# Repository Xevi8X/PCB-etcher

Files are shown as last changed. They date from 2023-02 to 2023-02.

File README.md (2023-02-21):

# PCB-etcher

This is the project of a small, but powerful thermostat based on ESP01 with phase controlled output and simple web application. Implements bang-bang controller with hysteresis, PID controller with anti-windup feature and autotune (hopefully, in future). Thermostat was design to control temperature in DIY PCB Etcher.

Project contains source code and electric circuit with PCB project, design in EAGLE PCB.

### Web application:

##### Info screen:
info

##### Charts:
chart

##### Controller setting:
controller

### Device:




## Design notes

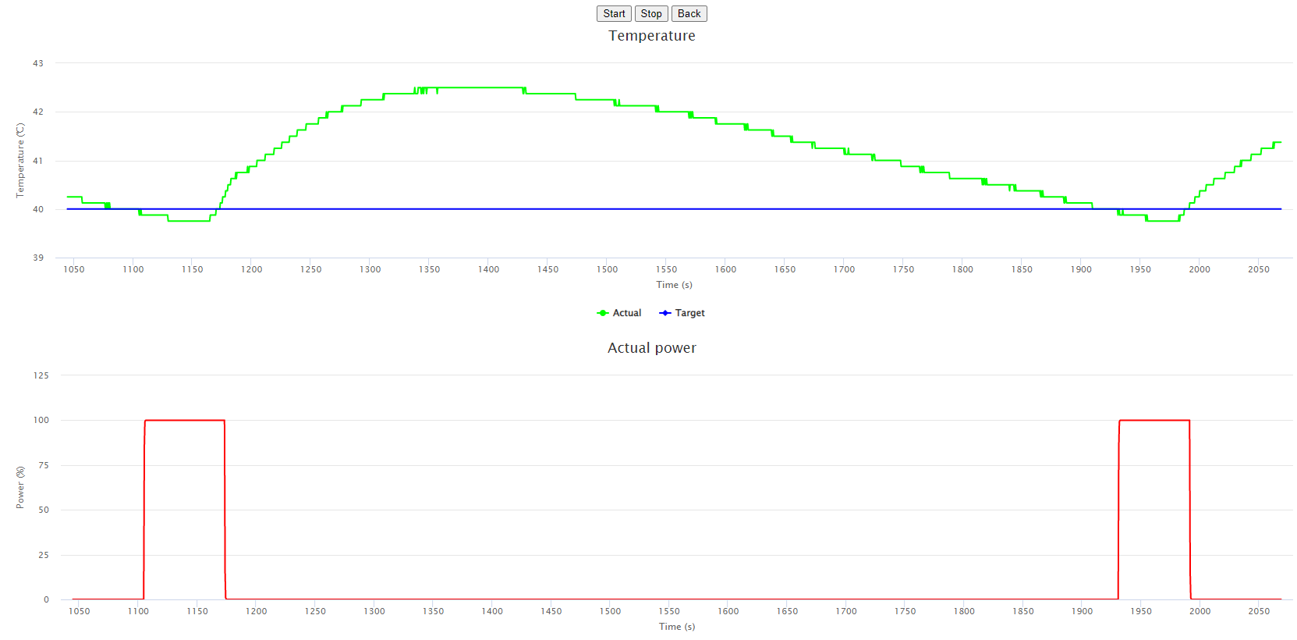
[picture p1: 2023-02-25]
docs/bang_bang_charts.png

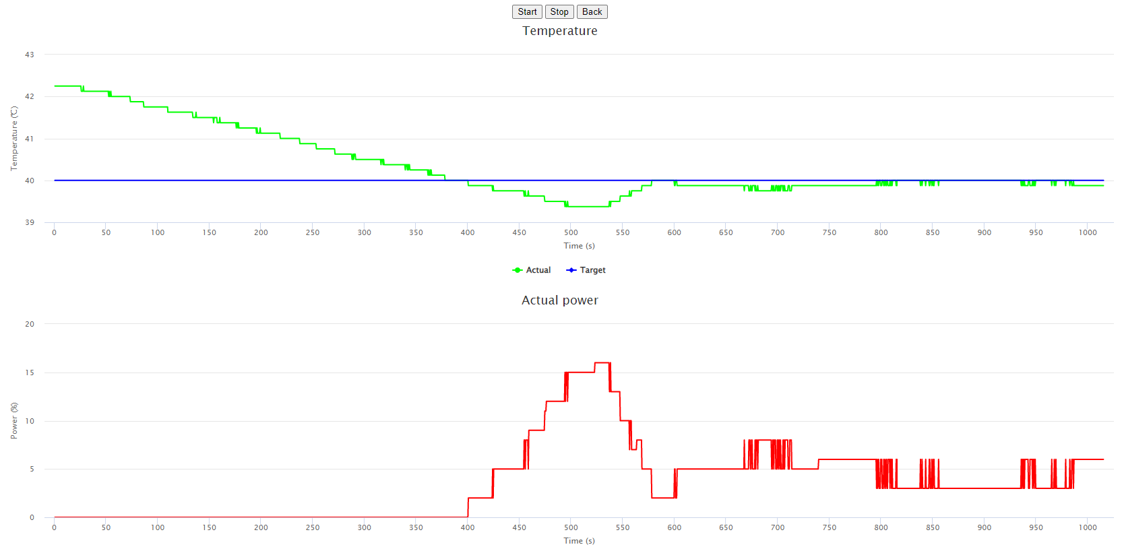
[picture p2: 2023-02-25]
docs/pid_charts.png

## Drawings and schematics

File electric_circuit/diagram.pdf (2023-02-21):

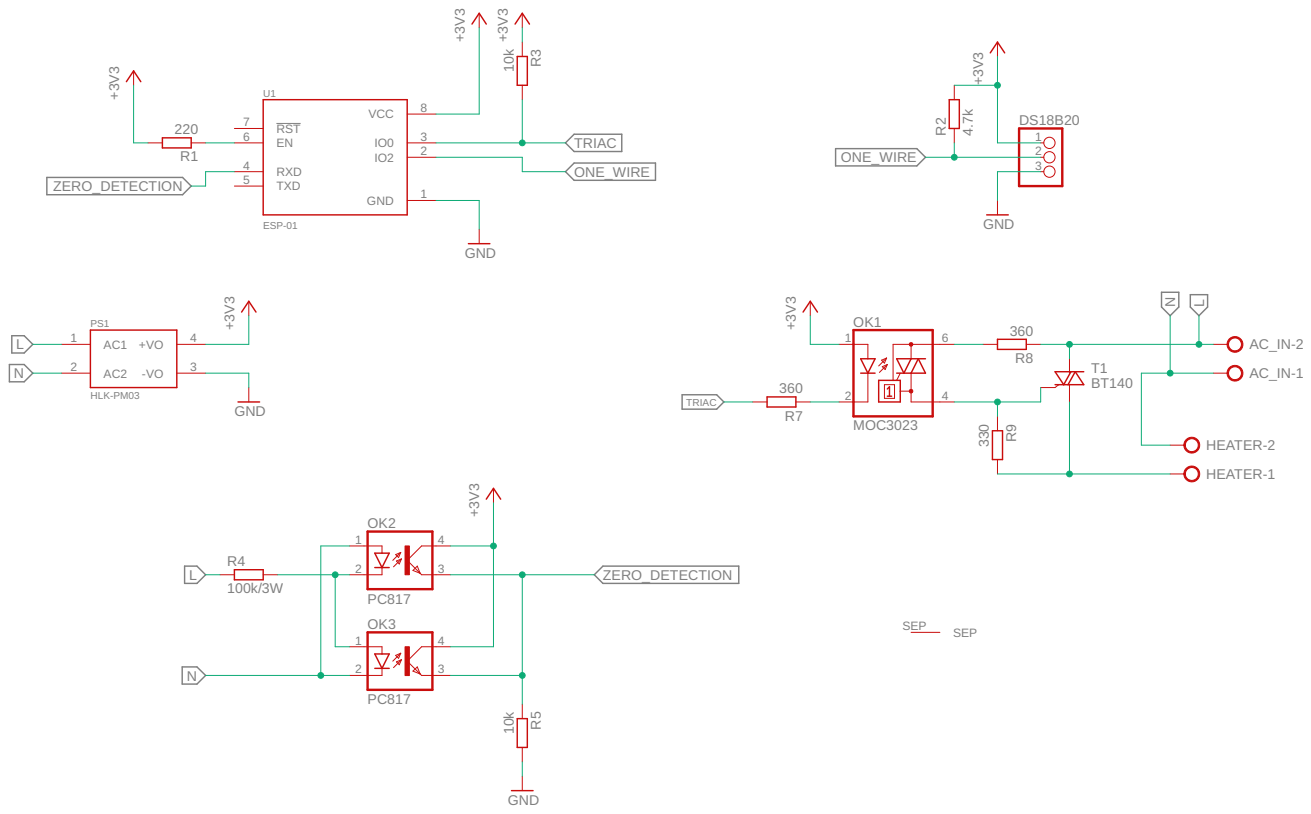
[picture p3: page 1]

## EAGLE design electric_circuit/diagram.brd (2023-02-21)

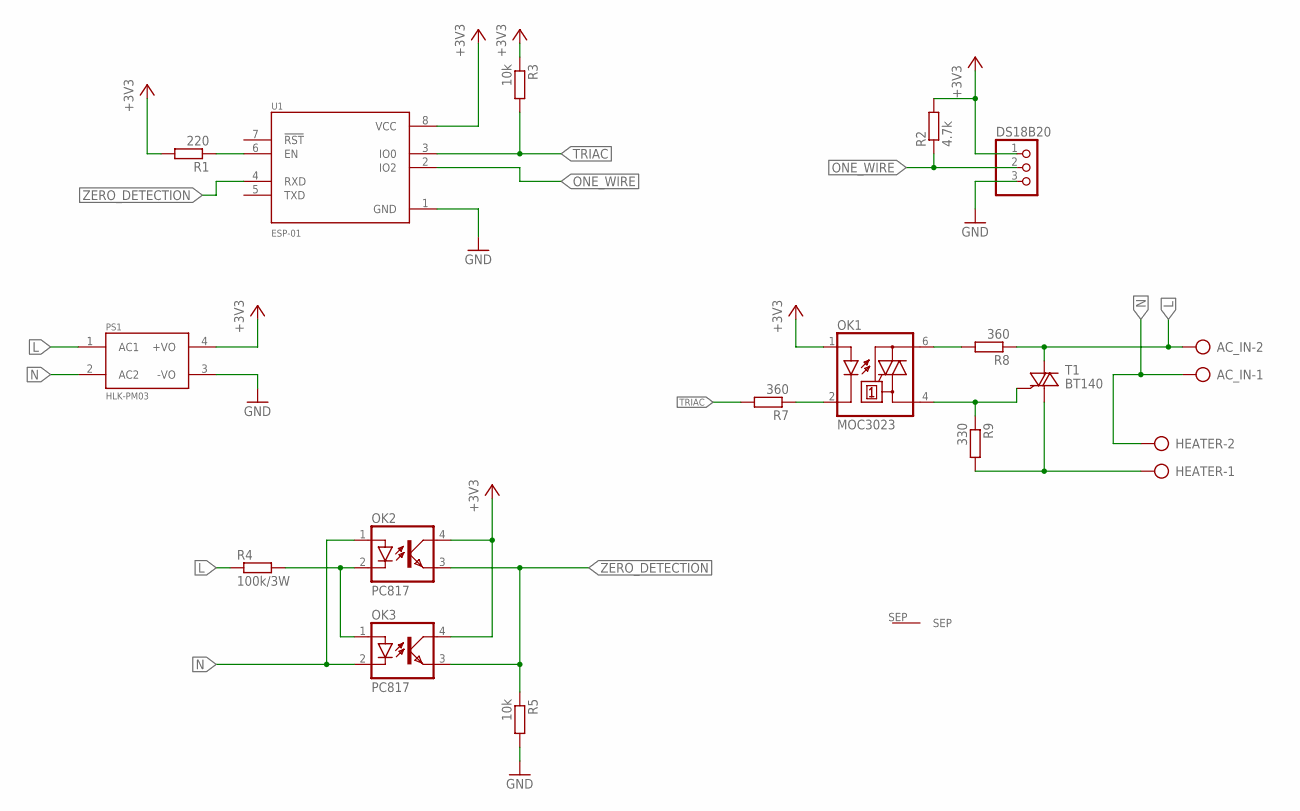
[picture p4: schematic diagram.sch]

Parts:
AC_IN: AK300/2
DS18B20: PINHD-1X3; 1X03
HEATER: AK300/2
OK1: MOC3023; DIL06
OK2, OK3: PC817; DIL04
PS1: HLK-PM03; CONV_HLK-PM03
R1: 220; R1206
R2: 4.7k; R1206
R3: 10k; 0204/5
R4: 100k/3W; 0414/15
R5: 10k; 0204/7
R7, R8: 360; M1206
R9: 330; M1206
T1: BT140; TO220BV
U1: ESP-01; XCVR_ESP8266-01/ESP-01
U$1: TEST; V7142

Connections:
+3V3: DS18B20.1, OK1.1 (A), OK2.4 (COL), OK3.4 (COL), PS1.4 (+VO), R1.2, R2.2, R3.1, U1.8 (VCC)
GND: DS18B20.3, PS1.3 (-VO), R5.2, U1.1 (GND)
L: AC_IN.2, PS1.1 (AC1), R4.1, R8.1, T1.T2 (A2)
N: AC_IN.1, HEATER.2, OK2.1 (A), OK3.2 (C), PS1.2 (AC2)
unnamed: R1.1, U1.6 (EN)
unnamed: OK2.2 (C), OK3.1 (A), R4.2
unnamed: OK1.6 (A2), R8.2
unnamed: OK1.4 (A1), R9.1, T1.G
unnamed: HEATER.1, R9.2, T1.T1 (A1)
unnamed: OK1.2 (C), R7.1
ONE_WIRE: DS18B20.2, R2.1, U1.2 (IO2)
TRIAC: R3.2, R7.2, U1.3 (IO0)
ZERO_DETECTION: OK2.3 (EMIT), OK3.3 (EMIT), R5.1, U1.4 (RXD)

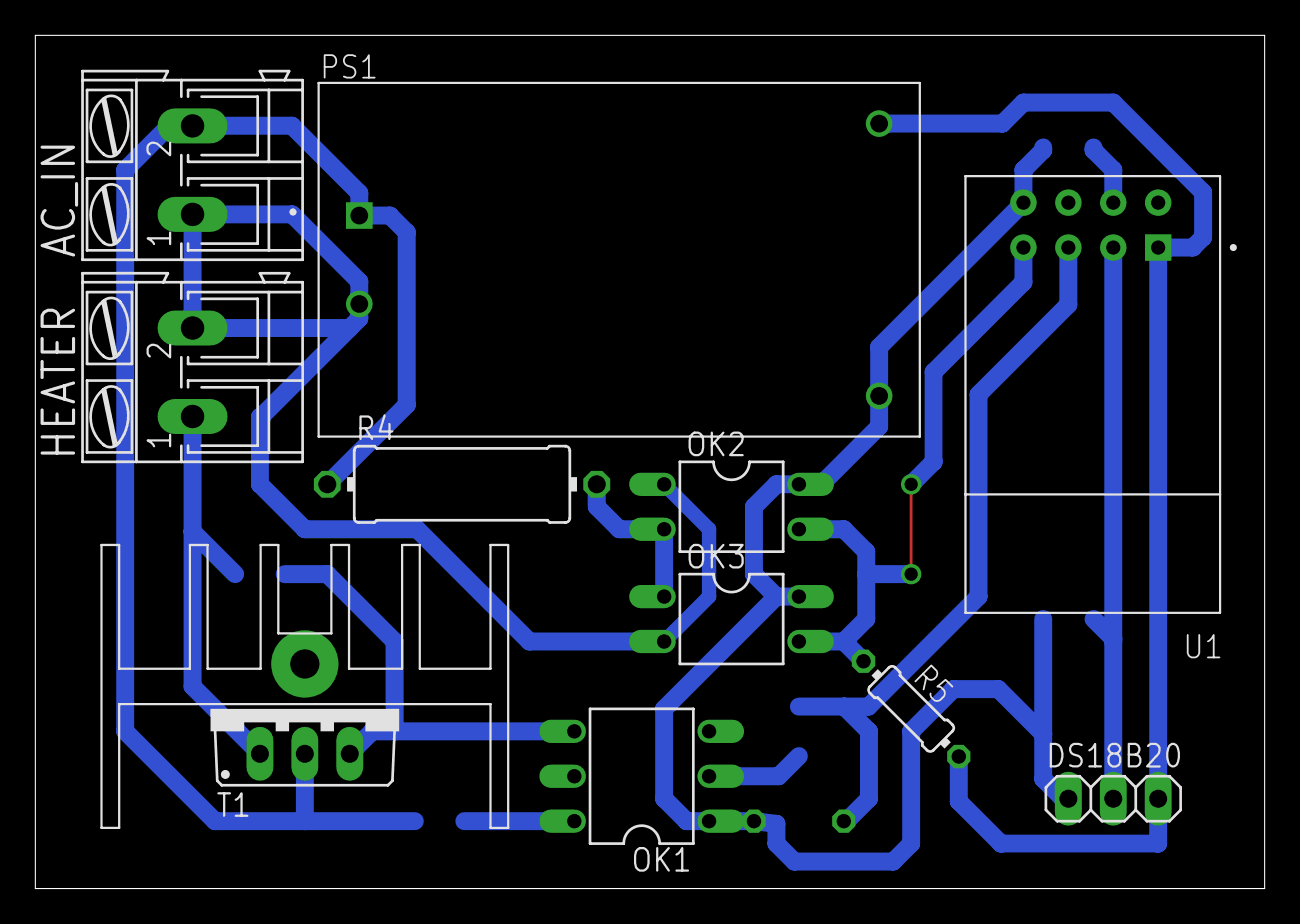
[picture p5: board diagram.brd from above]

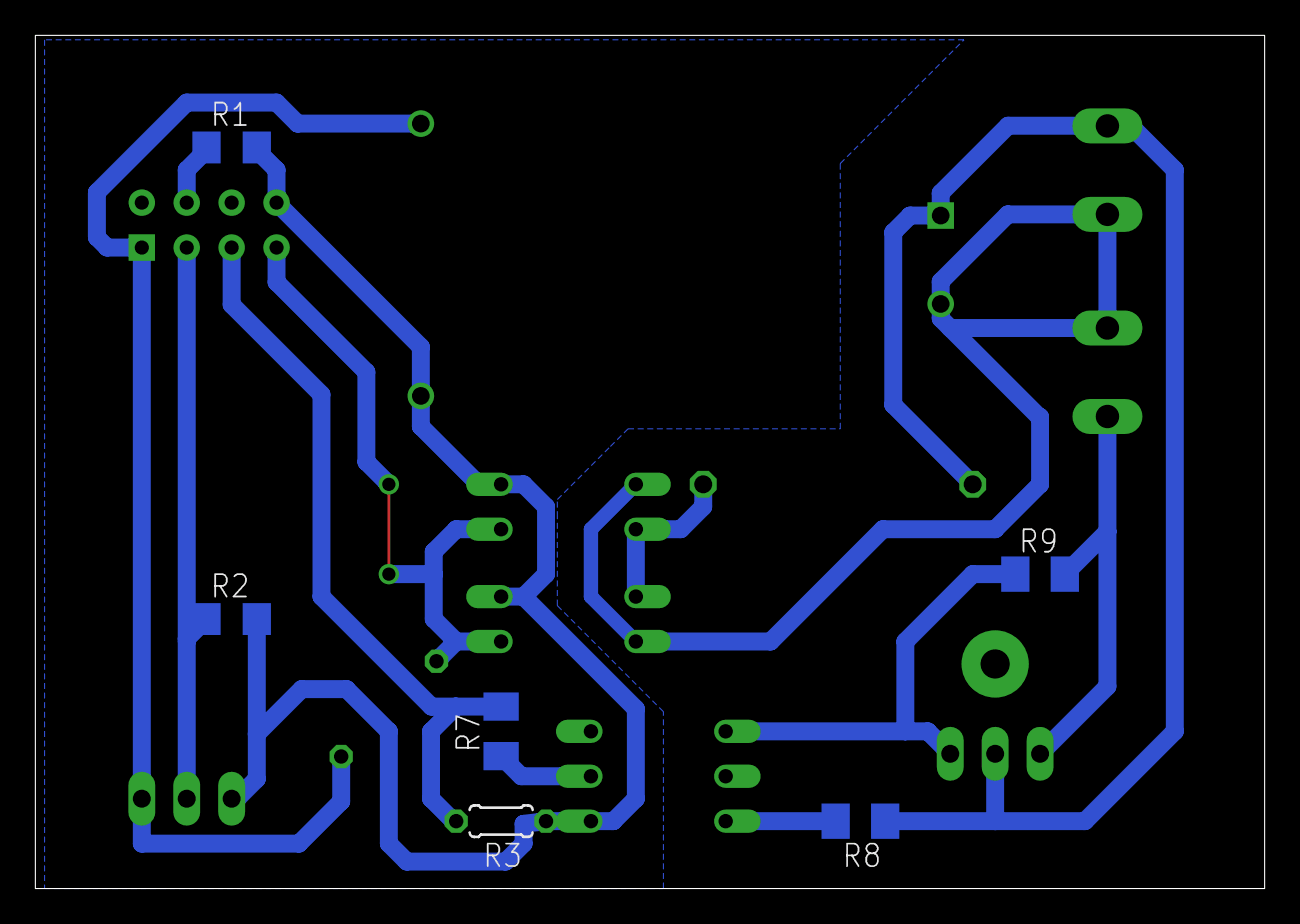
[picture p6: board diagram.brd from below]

Board: 2 copper layers, 69.5 x 48.2 mm, 18 parts (6 on the bottom side), 13 nets.

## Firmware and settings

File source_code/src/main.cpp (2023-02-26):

#include <Arduino.h>

#include "config.h"
#include "host.hpp"
#include "IO.hpp"
#include "controller.hpp"



State state;
unsigned long previousMillis = 0;

void setup() 
{
  IO_init();
  initControllers();
  startServer();
}

void loop() 
{
  handleClientsServer();
  unsigned long now = millis();
  if(now - previousMillis > MEASURE_PERIOD_IN_MILLIS)
  {
    previousMillis = now;
    measure();
    controllerWork();
  }
}

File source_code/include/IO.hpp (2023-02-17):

//Configuration
//==================================================
#define TRIAC_DELAY 3 //in ms, selected experimentally
//==================================================

//PINOUT
//==================================================
#define ONE_WIRE_PIN 2
#define TRIAC_PIN 0
#define ZERO_DETECTION_PIN 3
//==================================================

void IO_init();
void measure();

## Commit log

2023-02-20 PID controller added
2023-02-20 Interval corection, exact power step
2023-02-20 quick controller switch part 1
2023-02-21 Electric circuit with PCB project (EAGLE PCB)
    [diagram.brd, diagram.sch]
2023-02-25 Tuning pi controller - relay method
